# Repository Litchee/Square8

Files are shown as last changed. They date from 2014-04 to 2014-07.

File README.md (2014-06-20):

8 SQUARE - Heartbeat Necklace Soldering Kit
-------------


8 SQUARE is a lovely and eye catching necklace that shows off your geek attitude. We designed it to help you build up your confidence as a hardware maker. With the soldering iron held in your hand, and detailed tutorial aside, you can make a red heart bounce on the 8x8 LED matrix. 

**Easy to Solder**

8 SQUARE is friendly when it comes to soldering. Components chosen to fulfill the function are all easiest to solder and appropriate distance between each two pads is kept to ensure people without any soldering experience can get it run with only a little effort.



**Arduino Compatible Microcontroller**

8 SQUARE features a classic Atmega328 as its processor. You can totally reprogram it as a Arduino UNO - the most widely adapted Arduino board for now. Thousands of tutorials and libraries over the community are easily to found when you need help to support your next Arduino project with 8 SQUARE.

**Friendly to Sewing**

7 signal pins and 4 power pins are routed our as much larger circular pads along 8 SQUARE. They are designed for further exploration with fabric. The through hole of these signals are large enough to let you put through any regular needles and tie a knot to confirm the connection.  



<br>
**Part List**

- Base board x 1
- 1k ohm resistor x 4
- 2k ohm resistor x 1
- 10k ohm resistor x 1
- 100nF capacitor x 4
- 3mm red LED x 1
- 3mm green LED x 1
- Push button x 1
- Switch x 1
- Coin battery holder x 1
- LIR2032 coin battery x 1
- 8 pin female header x 2
- 8x8 LED matrix x 1
- leather rope x 1
- ring x 1
- tutorial x 1



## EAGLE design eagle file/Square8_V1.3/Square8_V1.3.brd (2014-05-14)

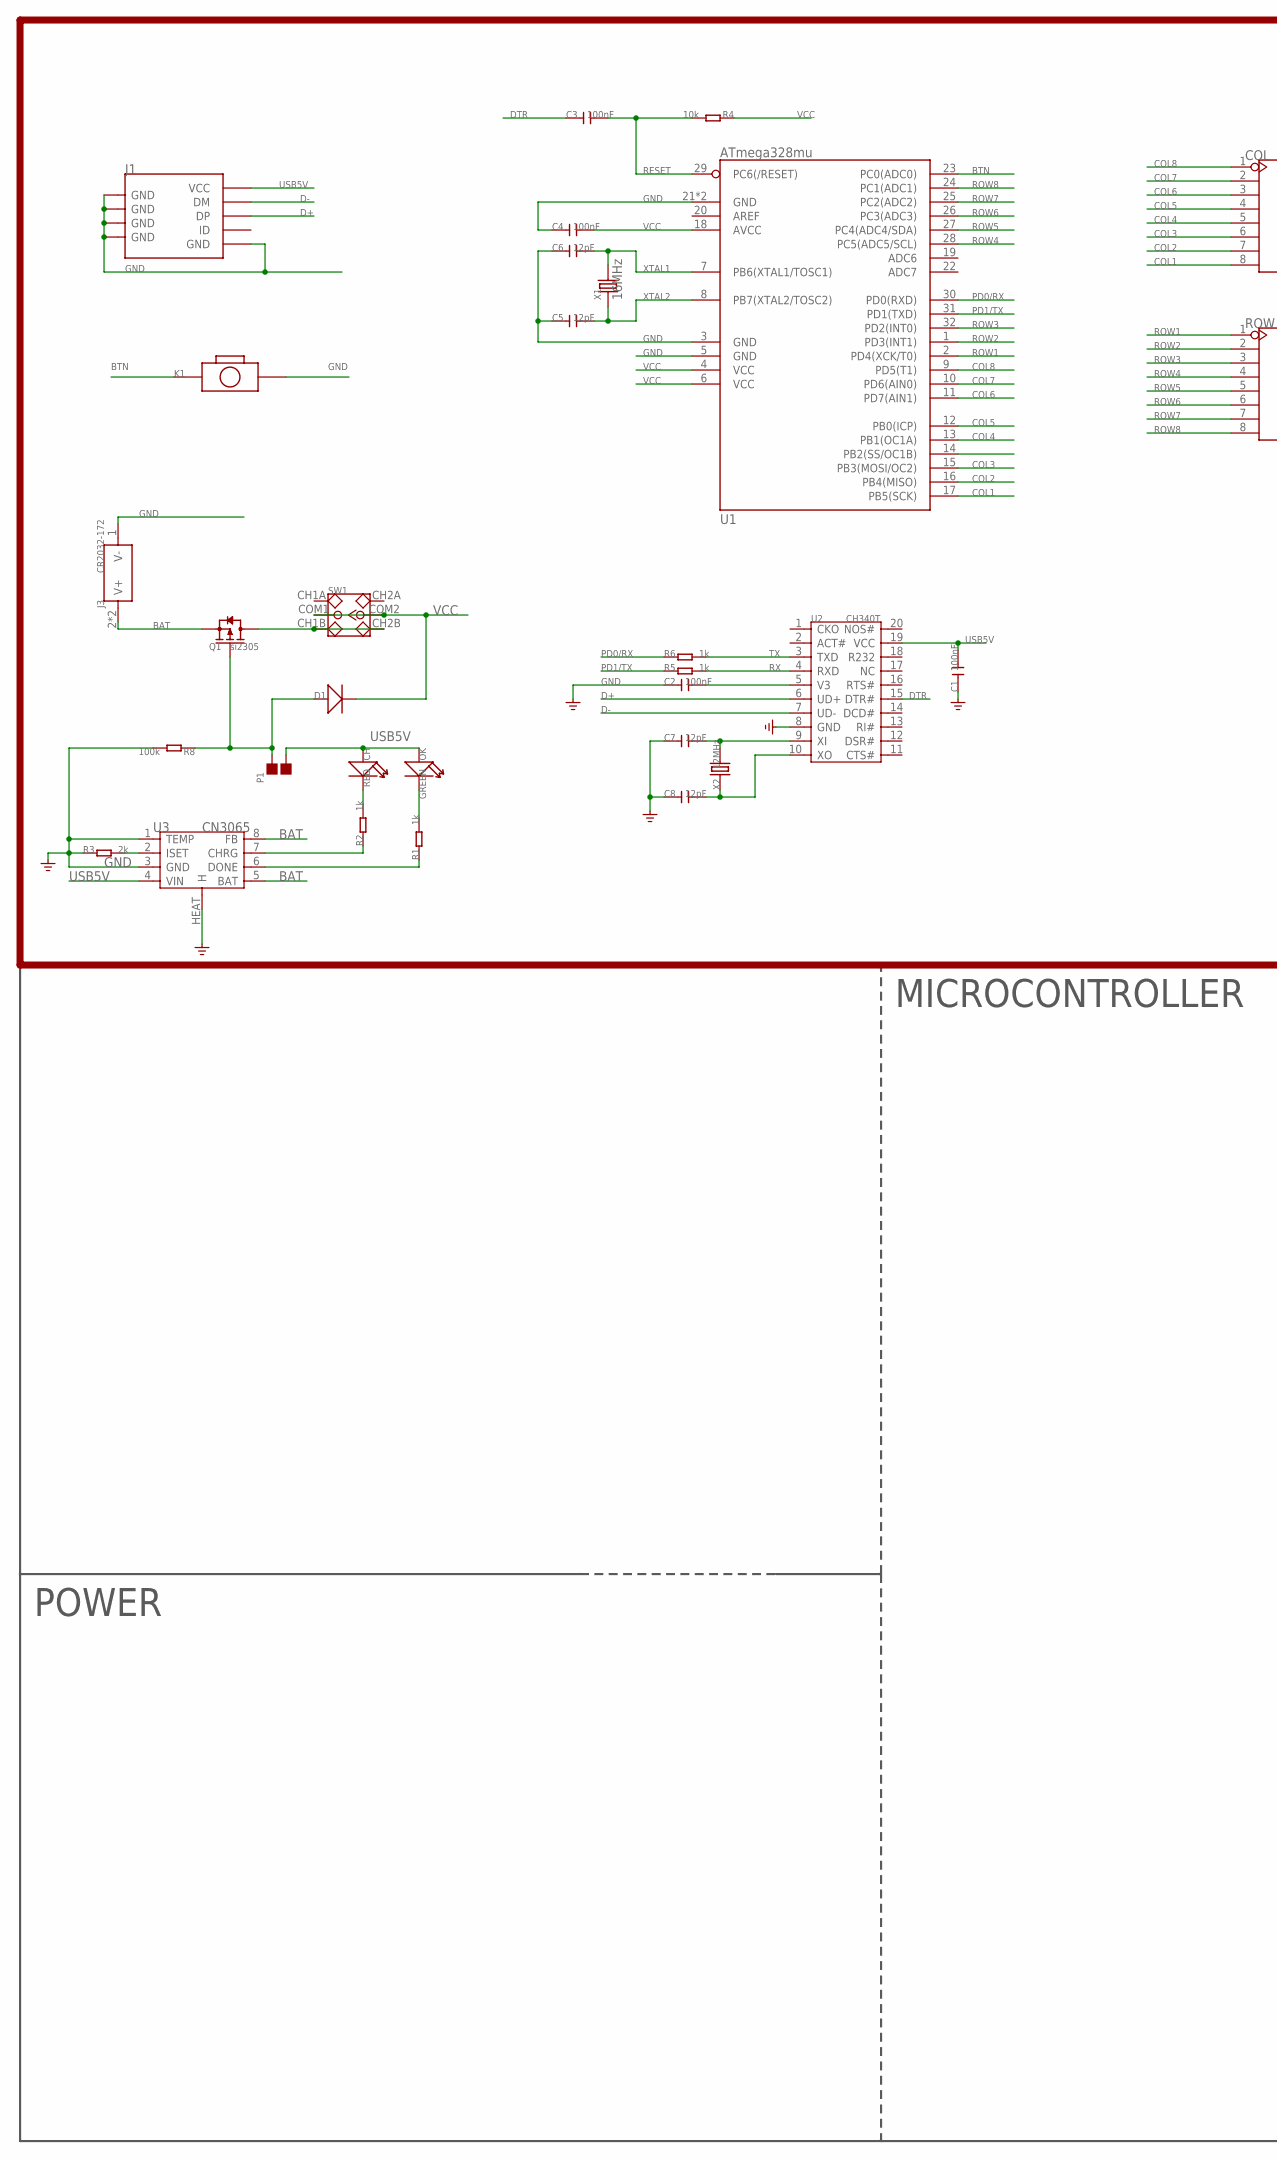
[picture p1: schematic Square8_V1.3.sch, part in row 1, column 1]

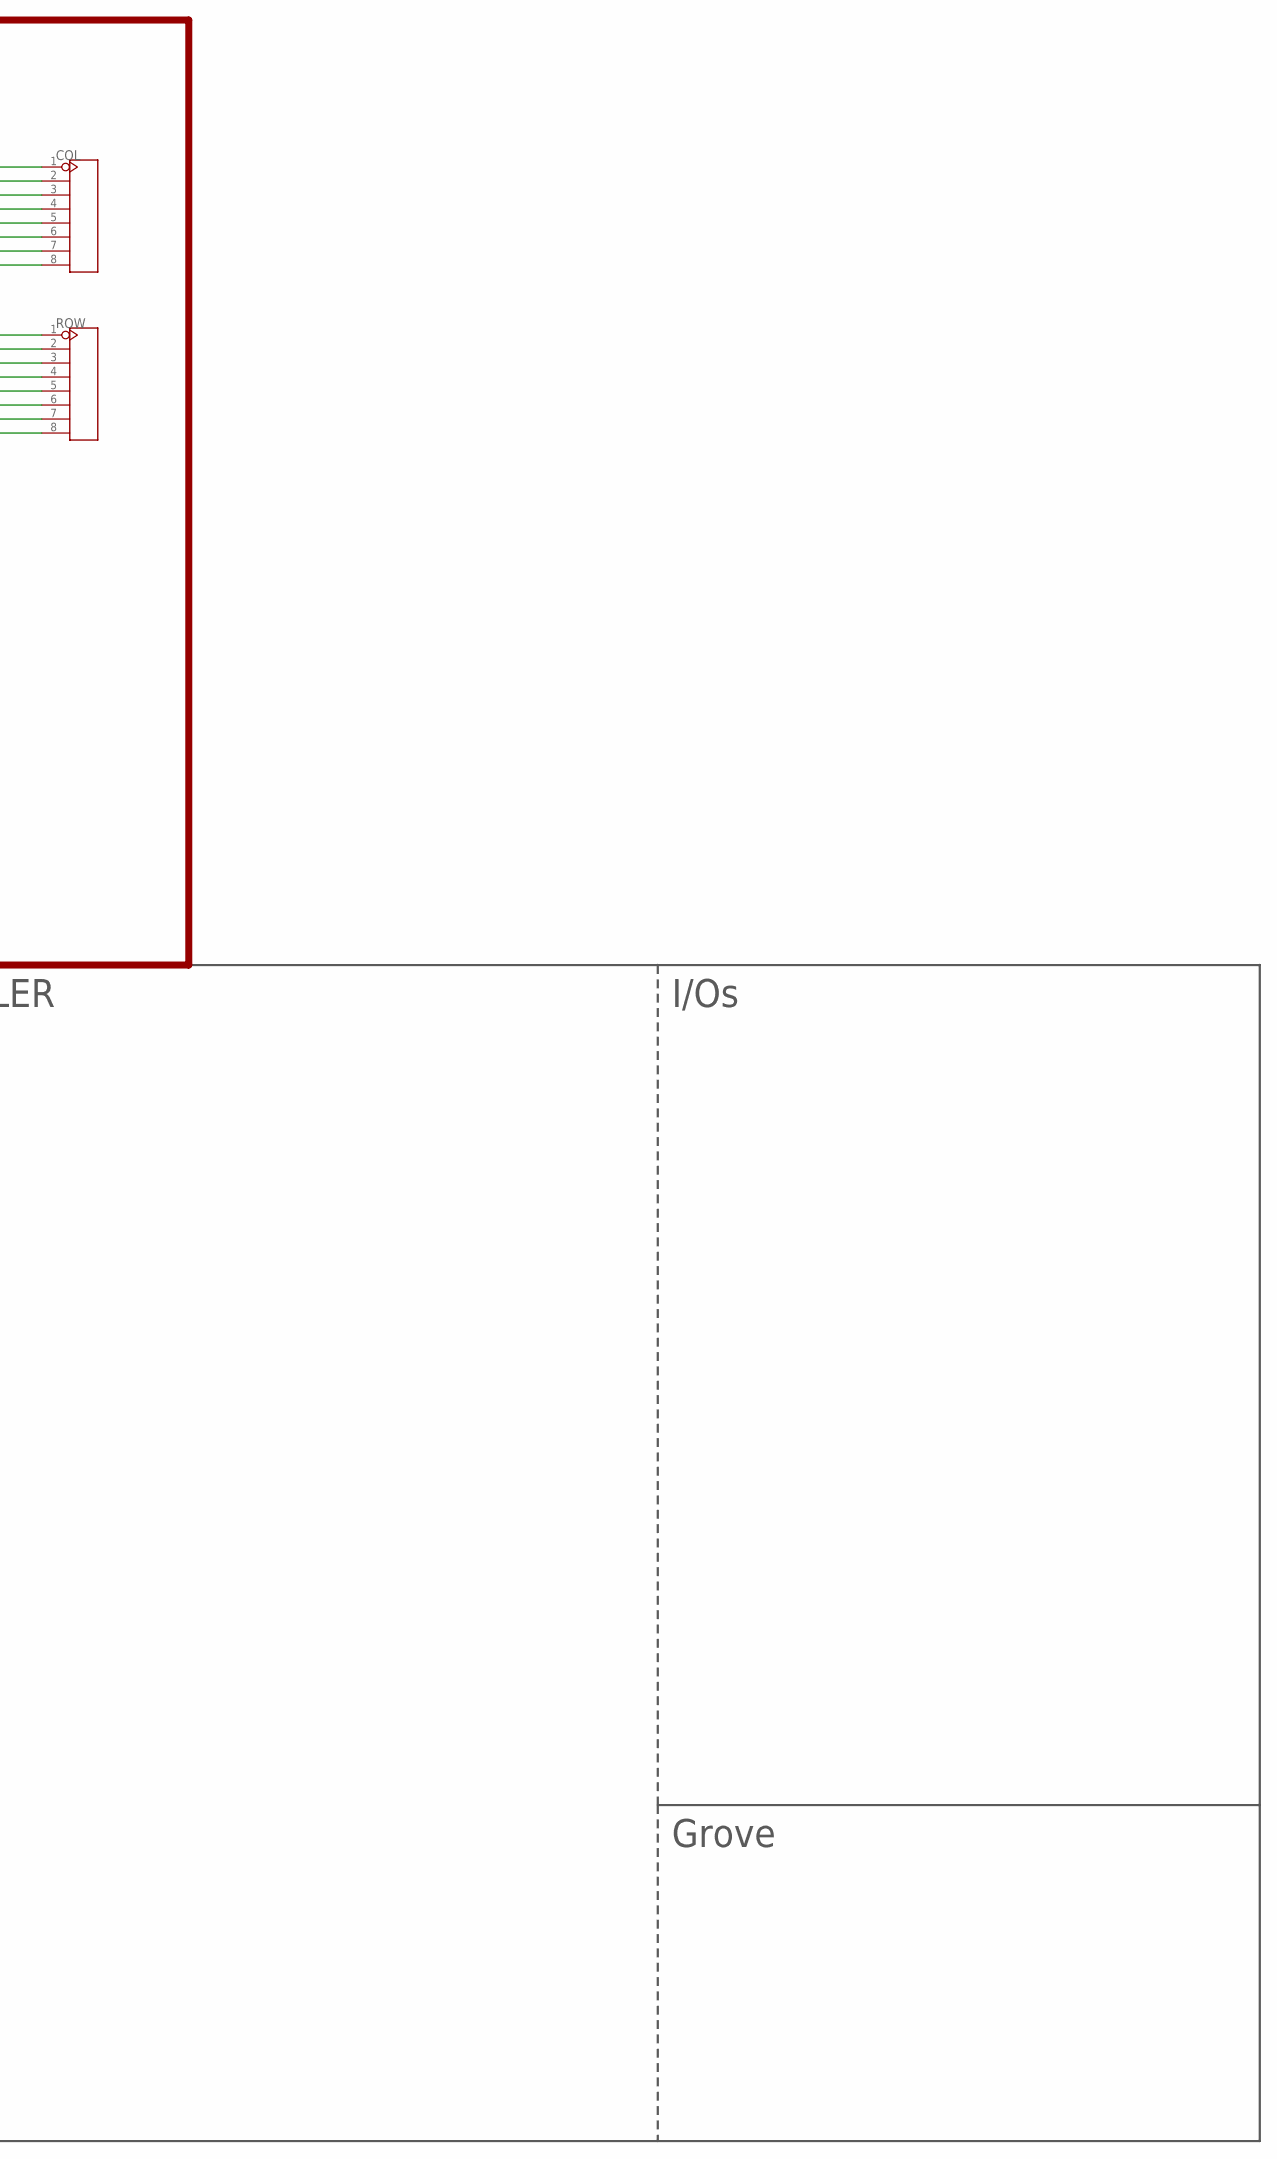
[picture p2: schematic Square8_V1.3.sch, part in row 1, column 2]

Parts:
C1, C2, C3, C4: 100nF; CERAMIC-2.54
C5, C6, C7, C8: 12pF; C0603
CH: RED; LED-2P-2.54-3MM
COL: HEADER-8P-2.54; 8P-2.54
D1: D'B130L-13-F'; SMA
J1: USB-MINIUSB-5P-MICRO; MICRO-USB
J3: CR2032-172; 2032-D20-CIRCLE
K1: BUTTON-2P'TS-1101F'; 2P-3.4X6.0X3.55H-90D
OK: GREEN; LED-2P-2.54-3MM
P1: PAD-JUMPER-2P; 2P-SMD-1.78X1.27
Q1: si2305; SOT23
R1, R2, R5, R6: 1k; R0204/7
R3: 2k; R0204/7
R4: 10k; R0204/7
R8: 100k; R0603
ROW: HEADER-8P-2.54; 8P-2.54
SW1: SWITCH-2CH-6P'90D'; 6P-2CH-2.5-9.1X3.5X3.2H-90D
U1: ATmega328mu; MLF32X-W/HEAT
U2: CH340T; SSOP20
U3: CN3065; DFN8
X1: 16MHz; HC49S
X2: 12MHz; HC49S

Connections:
BAT: J3.2 (V+), J3.3 (V+), Q1.2 (S), U3.5 (BAT), U3.8 (FB)
BTN: K1.P$1 (1), U1.23 (PC0(ADC0))
CH_STATE: R1.1, U3.6 (DONE)
COL1: COL.8, U1.17 (PB5(SCK))
COL2: COL.7, U1.16 (PB4(MISO))
COL3: COL.6, U1.15 (PB3(MOSI/OC2))
COL4: COL.5, U1.13 (PB1(OC1A))
COL5: COL.4, U1.12 (PB0(ICP))
COL6: COL.3, U1.11 (PD7(AIN1))
COL7: COL.2, U1.10 (PD6(AIN0))
COL8: COL.1, U1.9 (PD5(T1))
D+: J1.3 (DP), U2.6 (UD+)
D-: J1.2 (DM), U2.7 (UD-)
DTR: C3.1, U2.15 (DTR#)
GND: C1.1, C2.1, C4.1, C5.1, C6.1, C7.1, C8.1, J1.5 (GND), J1.S1 (GND), J1.S2 (GND), J1.S3 (GND), J1.S4 (GND), J1.S5 (GND), J1.S6 (GND), J3.1 (V-), K1.P$2 (2), R3.1, R8.2, U1.3 (GND), U1.5 (GND), U1.21 (GND), U1.HEAT (GND), U2.8 (GND), U3.1 (TEMP), U3.3 (GND), U3.HEAT (H)
unnamed: R2.1, U3.7 (CHRG)
unnamed: OK.K (-), R1.2
unnamed: D1.2 (+), P1.2, Q1.1 (G), R8.1
unnamed: CH.K (-), R2.2
unnamed: R3.2, U3.2 (ISET)
unnamed: C7.2, U2.9 (XI), X2.2
unnamed: C8.2, U2.10 (XO), X2.1
unnamed: Q1.3 (D), SW1.CH1B, SW1.CH2B
PD0/RX: R6.1, U1.30 (PD0(RXD))
PD1/TX: R5.1, U1.31 (PD1(TXD))
RESET: C3.2, R4.2, U1.29 (PC6(/RESET))
ROW1: ROW.1, U1.2 (PD4(XCK/T0))
ROW2: ROW.2, U1.1 (PD3(INT1))
ROW3: ROW.3, U1.32 (PD2(INT0))
ROW4: ROW.4, U1.28 (PC5(ADC5/SCL))
ROW5: ROW.5, U1.27 (PC4(ADC4/SDA))
ROW6: ROW.6, U1.26 (PC3(ADC3))
ROW7: ROW.7, U1.25 (PC2(ADC2))
ROW8: ROW.8, U1.24 (PC1(ADC1))
RX: R5.2, U2.4 (RXD)
TX: R6.2, U2.3 (TXD)
USB5V: C1.2, CH.A (+), J1.1 (VCC), OK.A (+), P1.1, U2.19 (VCC), U3.4 (VIN)
V3: C2.2, U2.5 (V3)
VCC: C4.2, D1.1 (-), R4.1, SW1.COM1, SW1.COM2, U1.4 (VCC), U1.6 (VCC), U1.18 (AVCC)
XTAL1: C6.2, U1.7 (PB6(XTAL1/TOSC1)), X1.2
XTAL2: C5.2, U1.8 (PB7(XTAL2/TOSC2)), X1.1

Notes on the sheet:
POWER
MICROCONTROLLER
I/Os
Grove

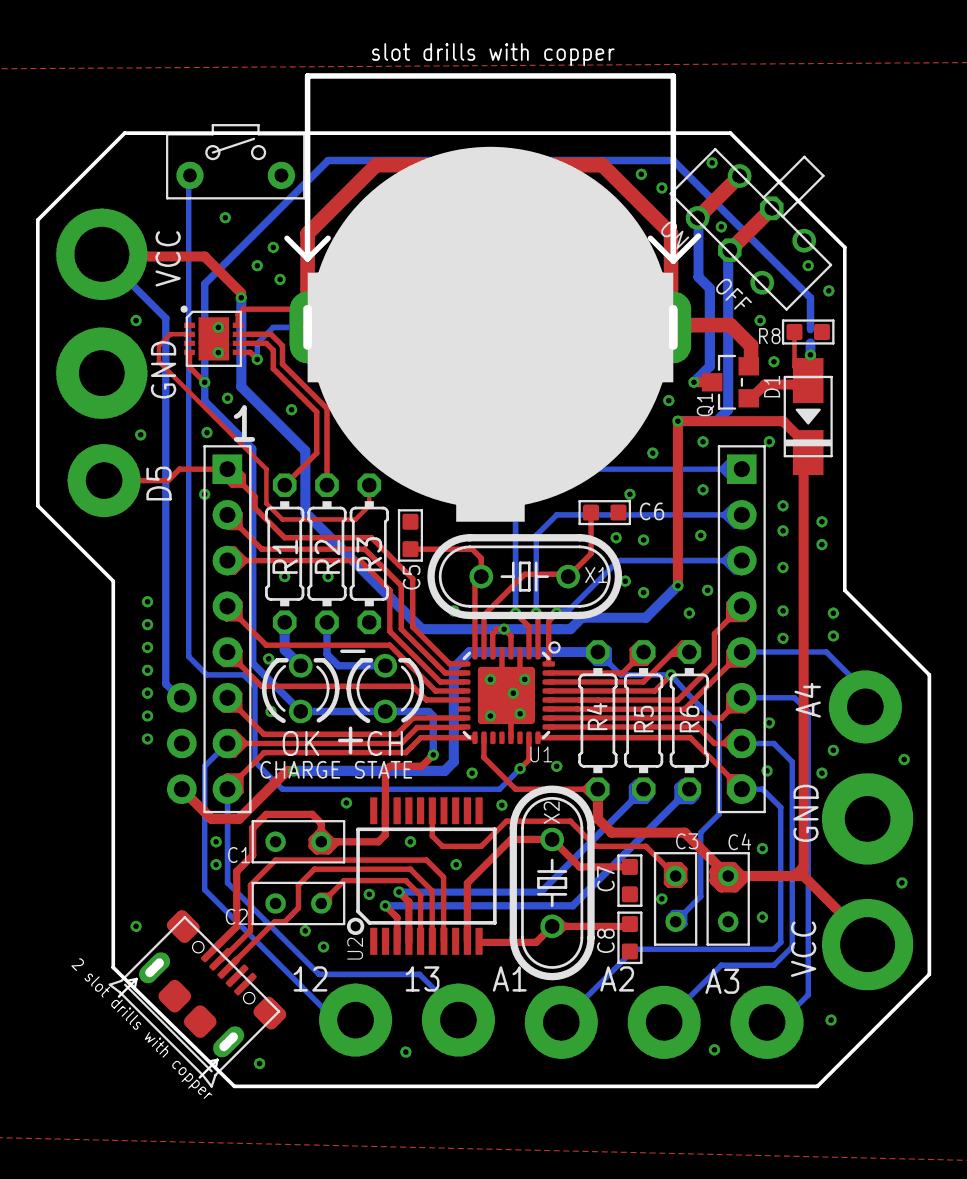
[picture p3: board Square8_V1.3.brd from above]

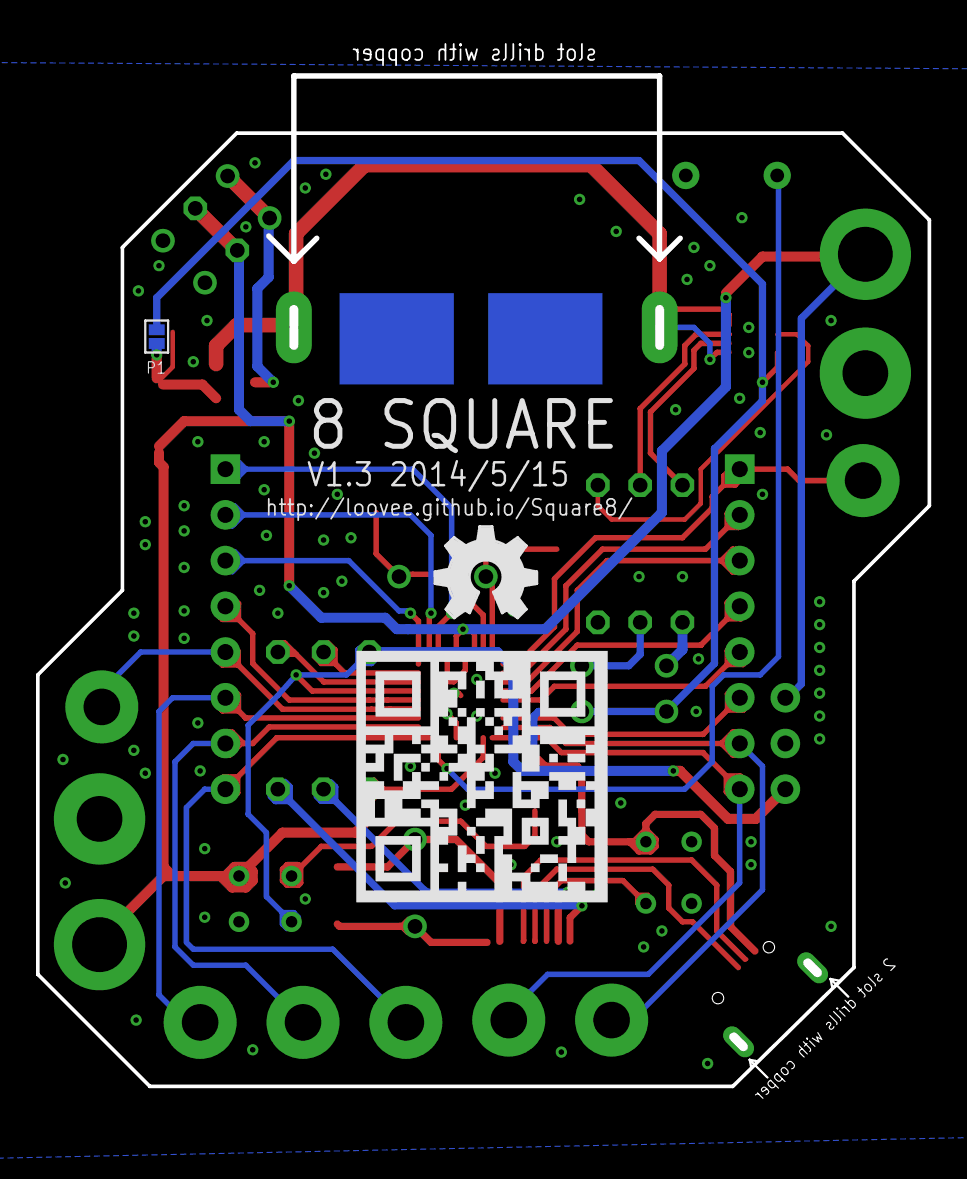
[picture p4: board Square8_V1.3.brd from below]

Board: 2 copper layers, 49.5 x 56.1 mm, 32 parts (2 on the bottom side), 41 nets.

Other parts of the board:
U$1: OSHW_FILLX200_NOTEXT

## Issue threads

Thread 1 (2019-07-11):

battery is not working

ILohs, 2019-07-11:
I'm currently hanging on the limitation in battery-powered mode. Several LR2032 tested without success.
Have an eye to my published article about this kit here:
https://www.hackster.io/ingo-lohs/blinking-heart-with-the-8-square-kit-26269a

Any ideas?

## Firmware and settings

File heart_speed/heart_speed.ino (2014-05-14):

/*
  szmf heart

  loovee
  2014-3-20

  for more information, please refer to
  http://www.seeedstudio.com/wiki/index.php?title=Sidekick_Advanced_Kit&uselang=en
  
  About the pin connect, refer to http://arduino.cc/en/Tutorial/RowColumnScanning
  
  button connect to A0
  
*/

#include <LED_Matrix.h>
#include <LED_Matrix_dfs.h>
#include <MsTimer2.h>

const int pinBtn = A0;


int speed = 0;


// 0 for normal
// 1 for 45 angle
int heartType = 0;

int dir = DIR_RIGHT;

int delay_time1 = 200;
int delay_time2 = 1000;

// matrix of big heart
unsigned char big_heart[8] = {

0b00000000,
0b01100110,
0b11111111,
0b11111111,
0b11111111,
0b01111110,
0b00111100,
0b00011000,
};

// matrix of small heart
unsigned char small_heart[8] = {

0b00000000,
0b00000000,
0b00100100,
0b01111110,
0b01111110,
0b00111100,
0b00011000,
0b00000000,
};

unsigned char big_heart_45[8] = 
{
0b00000000,
0b01111110,
0b01111110,
0b01111110,
0b01111110,
0b01111000,
0b01111000,
0b00000000,
};

unsigned char small_heart_45[8] = 
{
0b00000000,
0b00000000,
0b00111000,
0b00111000,
0b00110000,
0b00000000,
0b00000000,
0b00000000,

};




/*

#define DIR_NORMAL      0x00
#define DIR_LEFT        0x01
#define DIR_RIGHT       0x02
#define DIR_DOWN        0x03

*/

void speedCnt()
{
    speed++;
    if(speed>4)speed=0;
    
    delay_time2 = (5-speed)*200;
}

void typeCnt()
{
    heartType = 1-heartType;
    
    if(heartType == 1)                  // 45 angle
    {
        dir = DIR_DOWN;
        matrix.setDirDisp(dir);
        matrix.dispMatrix(big_heart_45);
    }
    else
    {
        dir = DIR_RIGHT;
        matrix.setDirDisp(dir);
        matrix.dispMatrix(big_heart);
    }
    
    
}


// matrix of empty

unsigned char full[8] = {0xff, 0xff, 0xff, 0xff, 0xff, 0xff, 0xff, 0xff};
unsigned char empty[8] = {0, 0, 0, 0, 0, 0, 0, 0};

int state = 1;

void checkBtnAndDelay(int ms)
{
    
    for(int i=0; i<ms; i++)
    {
        delay(1);

        if(!digitalRead(pinBtn))
        {
            delay(10);
            
            long timer_t = millis();
            if(!digitalRead(pinBtn))
            {
                
                if(0 == heartType)
                {
                    matrix.dispMatrix(big_heart);
                }
                else
                {
                    matrix.dispMatrix(big_heart_45);
                }
                
                
                int flg_setype = 0;
                while(!digitalRead(pinBtn))
                {
                    if((millis()-timer_t)>1000)         // more than 1s
                    {
                        typeCnt();
                        timer_t = millis();
                        
                        flg_setype = 1;

                    }
                }
            
                if(flg_setype)return;
                speedCnt();

            }

            return;
        }
    }
}
long tiemr_tmp = 1;


void setup()
{
    matrix.begin();
    matrix.setDirDisp(dir);
    Serial.begin(115200);
    pinMode(pinBtn, INPUT);
    digitalWrite(pinBtn, HIGH);
    Serial.println("8 square firmware v1.0");
    Serial.println("by loovee, Apr29, 2014");
    Serial.println("github.com/loovee/square8");
}


void loop()
{

    if(0 == heartType)
    {
        matrix.dispMatrix(big_heart);
    }
    else
    {
        matrix.dispMatrix(big_heart_45);
    }
    
    checkBtnAndDelay(150);
    
    if(0 == heartType)   
    {
        matrix.dispMatrix(small_heart);
    }
    else
    {
        matrix.dispMatrix(small_heart_45);
    }
    
    checkBtnAndDelay(50);
    matrix.dispMatrix(empty);
    checkBtnAndDelay(delay_time2);
            
    if(0 == heartType)   
    {
        matrix.dispMatrix(small_heart);
    }
    else
    {
        matrix.dispMatrix(small_heart_45);
    }
    checkBtnAndDelay(80);

    
}

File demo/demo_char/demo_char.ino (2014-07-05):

/*
  8 square - display char
  
  loovee
  2014-7-5

  for more information, please refer to
  https://github.com/Litchee/Square8
  
  About the pin connect, refer to http://arduino.cc/en/Tutorial/RowColumnScanning

*/

#include <LED_Matrix.h>
#include <LED_Matrix_dfs.h>
#include <MsTimer2.h>


void setup()
{
    matrix.begin(DIR_NORMAL);
}


char str[] = "8Square";

void loop()
{
    for(int i=0; i<(sizeof(str)-1); i++)
    {
        matrix.dispChar(str[i]);
        delay(500);
    }
    matrix.clear();
    delay(1500);
}

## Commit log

2014-04-09 add hex file and eagle file
    [Square8.brd, Square8.sch]
2014-04-09 add github url to eagle file
    [Square8.brd]
2014-04-16 add an two-dimension code to pcb
    [Square8.brd, Square8.sch]
2014-04-17 update eagle file
    [Square8.brd, Square8.sch]
2014-04-21 add a pmos, when usb inserted, power will on
    [Square8.brd, Square8.sch]
2014-04-21 improve pcb
    [Square8.brd, Square8.sch]
2014-04-28 add V1.2 eagle file
    [Square8.brd, Square8.sch, Square8_V1.2.brd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]
2014-04-28 add bom
    [BOM-V2.2.xlsx]
2014-05-14 update eagle file to 1.3, inprove the layout, expecially the RST line
    [Square8_V1.3.brd, Square8_V1.3.sch]
